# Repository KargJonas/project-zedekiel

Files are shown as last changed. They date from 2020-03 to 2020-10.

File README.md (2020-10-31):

# project-zedekiel
A pain-free 66% keyboard.

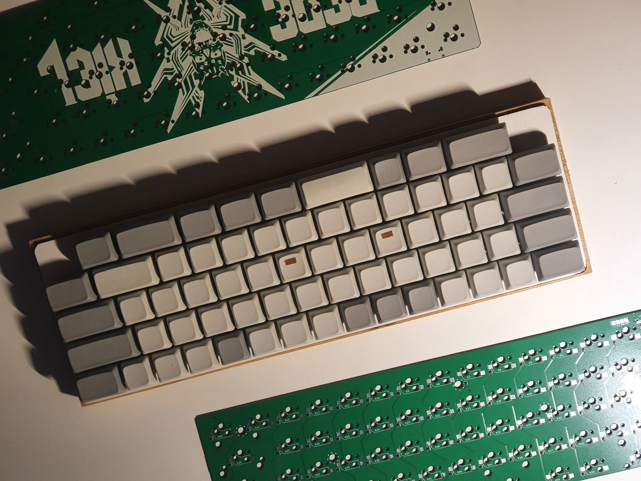
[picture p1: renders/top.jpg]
Built top view

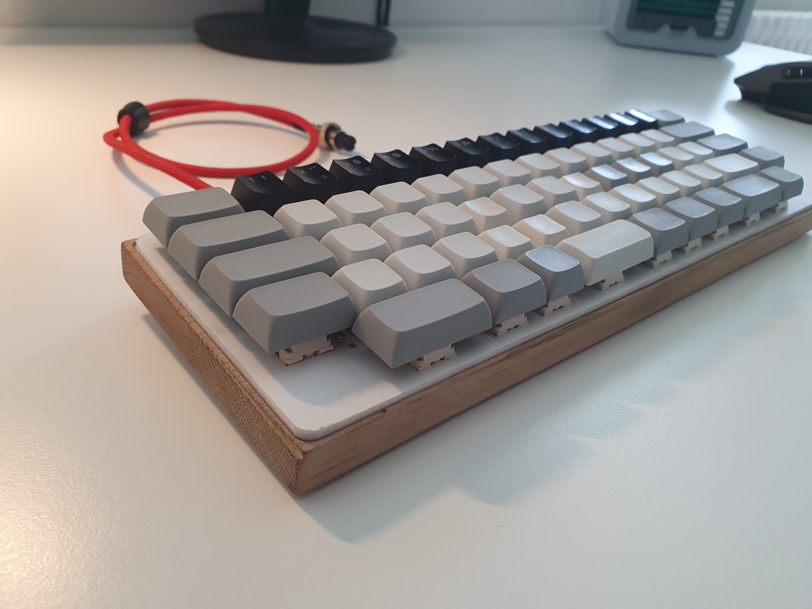
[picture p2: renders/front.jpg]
Built front view

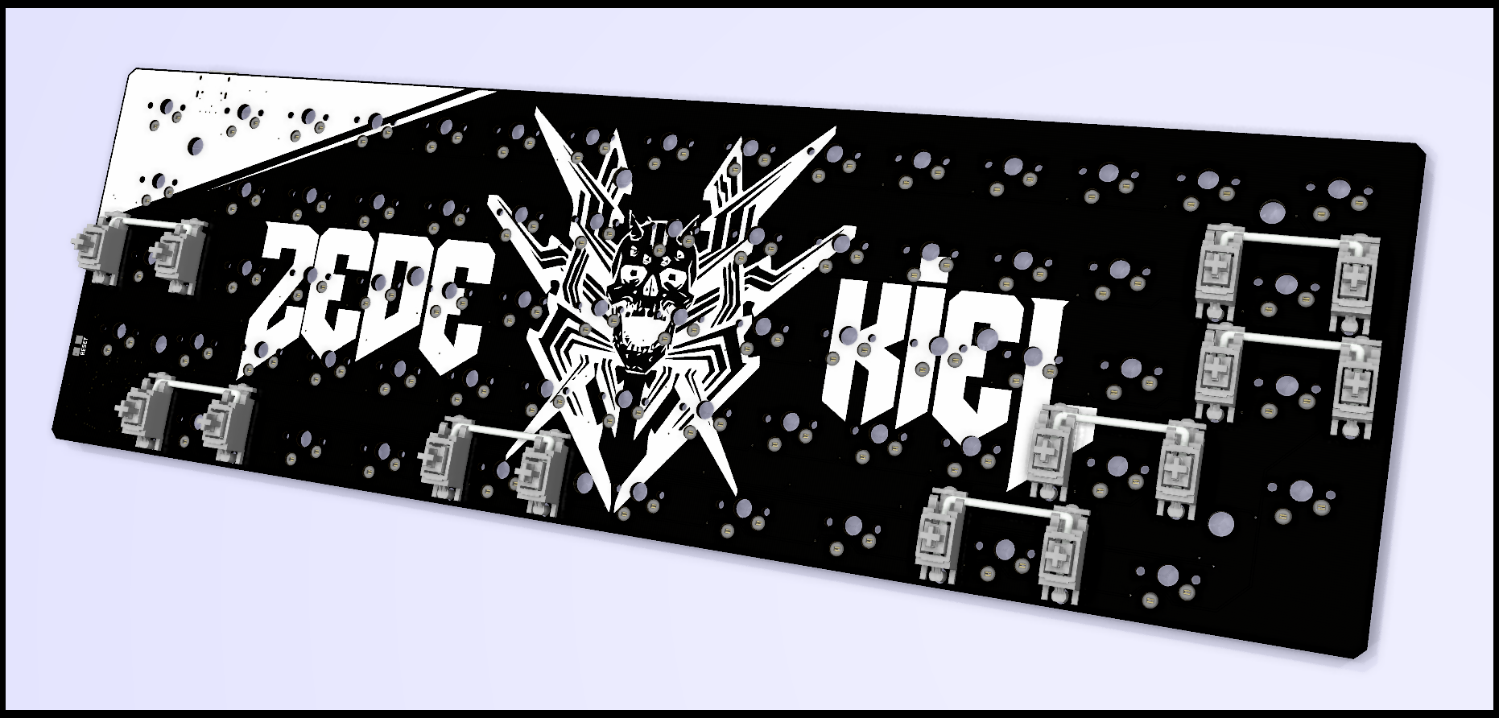
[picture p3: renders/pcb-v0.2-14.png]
Render

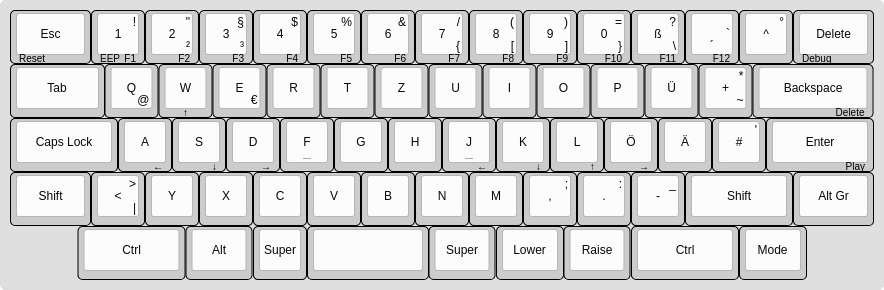
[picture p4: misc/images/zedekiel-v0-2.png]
Layout


## Flashing Guide
You will need linux for this (yes, when the keyboard is flashed, it will work in windows).
If you are using windows, you might want to take a look at [WSL](https://docs.microsoft.com/en-us/windows/wsl/).

- Clone the Zedekiel QMK fork: `git clone git@github.com:KargJonas/qmk_firmware`
- Open the directory: `cd qmk_firmware`
- Compile and flash Zedekiel default layout: `sudo make zedekiel:default:dfu`

If all goes well, your keyboard should now be ready to use.

## Tools used to make this
- KiCad
- LibreOffice
- LibreCad
- FreeCad
- GIMP
- QMK
- [www.keyboard-layout-editor.com](http://www.keyboard-layout-editor.com/)
- [builder.swillkb.com](http://builder.swillkb.com/)
- [qmk.fm/converter](https://qmk.fm/converter/)
- [www.engbedded.com/fusecalc](https://www.engbedded.com/fusecalc/)

## Resources
- [Keyboard PCB Guide](https://github.com/ruiqimao/keyboard-pcb-guide)
- [keebfol.io List of custom MKs](https://keebfol.io/)
- [QMK Getting Started](https://github.com/qmk/qmk_firmware/blob/76189d9a282cc32bf2ff88a84a6374ebb8908433/docs/getting_started_introduction.md)
- [Understanding QMK](https://github.com/qmk/qmk_firmware/blob/76189d9a282cc32bf2ff88a84a6374ebb8908433/docs/understanding_qmk.md)
- [QMK Keyboard Support](https://beta.docs.qmk.fm/configurator/qmk-api/reference_configurator_support)
- [QMK Config Guide](https://beta.docs.qmk.fm/developing-qmk/c-development/hardware_avr)
- [QMK Keycodes](https://github.com/qmk/qmk_firmware/blob/76189d9a282cc32bf2ff88a84a6374ebb8908433/docs/keycodes.md)
- [QMK ISP Flashing Guide](https://beta.docs.qmk.fm/using-qmk/guides/keyboard-building/isp_flashing_guide)
- [DFU Explained](https://electronics.stackexchange.com/questions/299712/how-is-the-atmega32u4-chip-recognized-via-usb)
- (More in `/misc/resources` folder)

## List of small issues and solutions
- KiCad footprint update not reflecting in 3D viewer =>
  - "e" on footprint
  - Edit footprint from Library
  - Edit footprint properties with the symbol in the topbar of the footprint editor
  - Go back to the pcb editor
  - "e" on footprint
  - Update footprint
  - 3D viewer should automatically update the 3D model
- FreeCad CSV import "broken" => export with {TAB} as delimiter.

# More Pictures
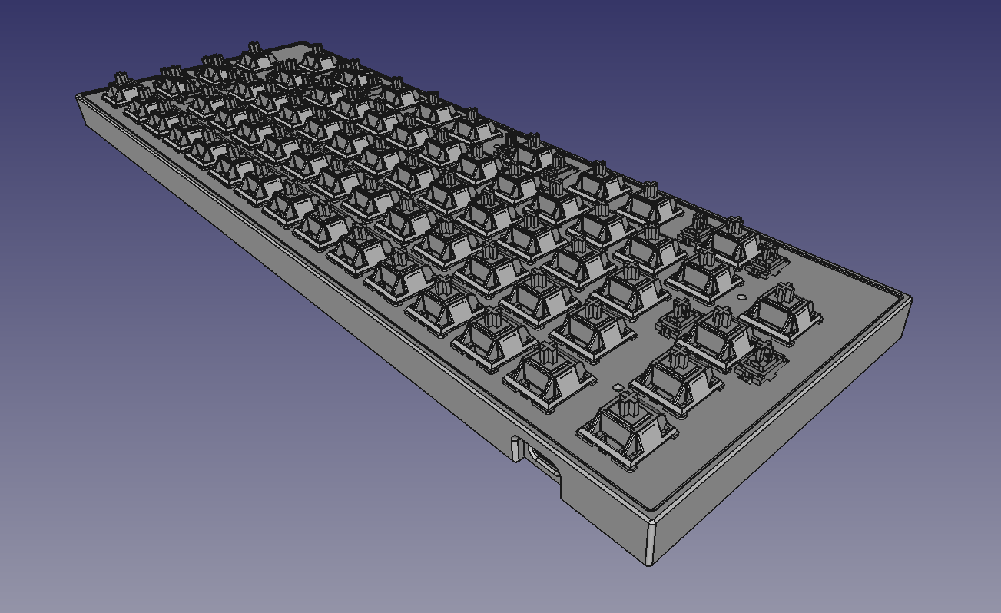
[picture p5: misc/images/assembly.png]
Assembly

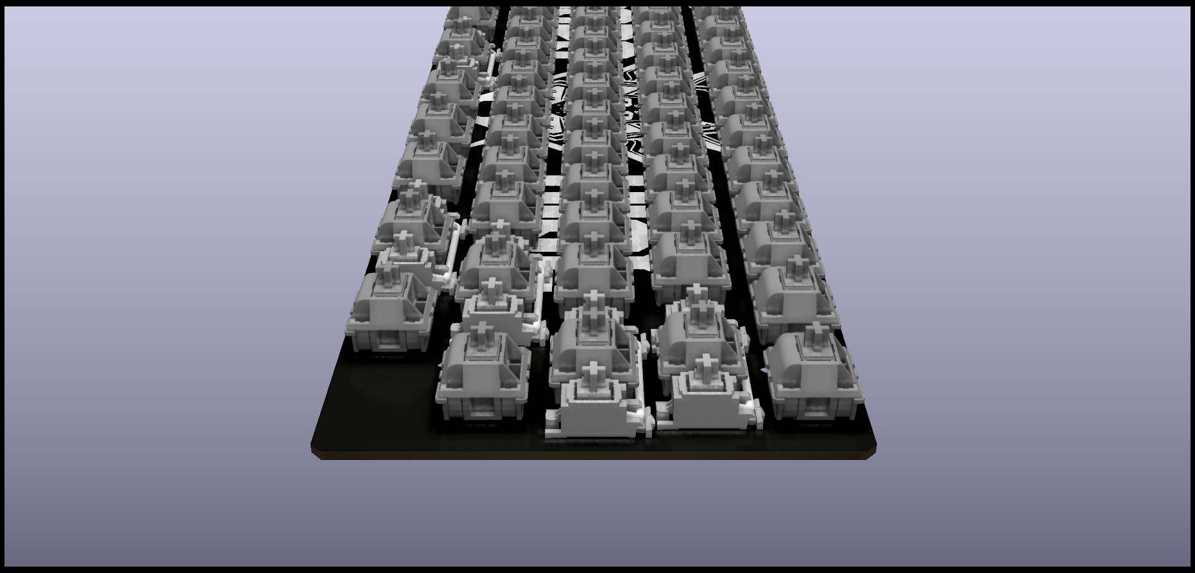
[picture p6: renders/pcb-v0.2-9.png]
Render

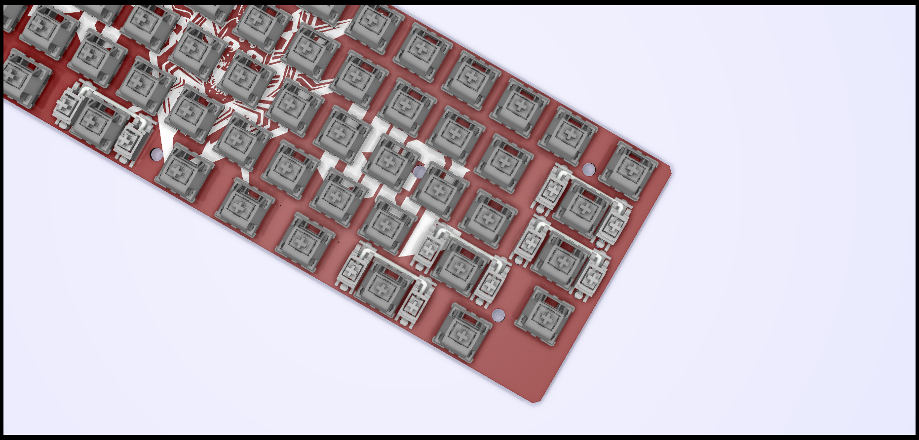
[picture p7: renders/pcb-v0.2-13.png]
Render

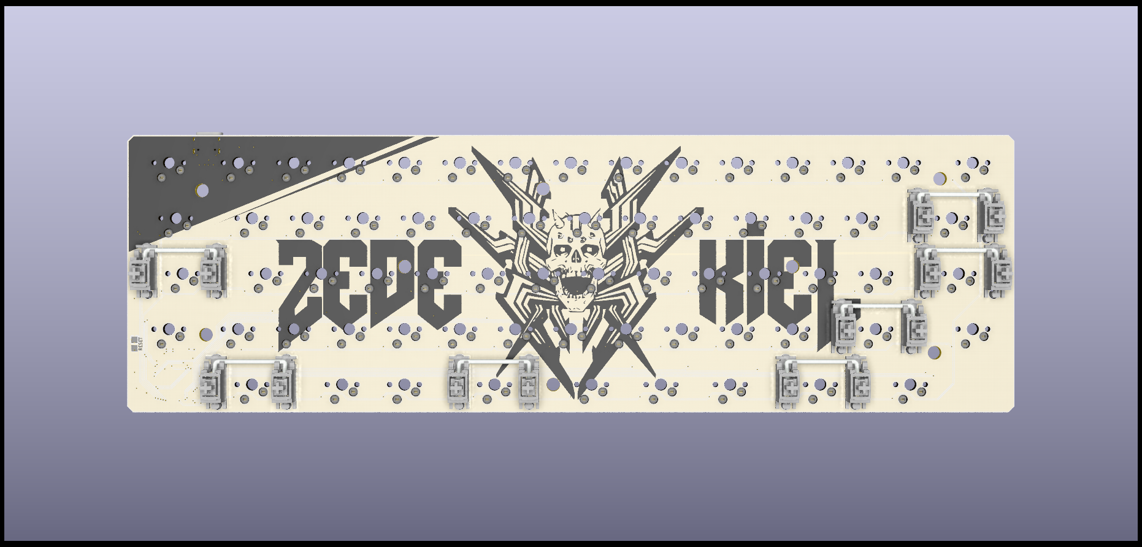
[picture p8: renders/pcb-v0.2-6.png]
Render

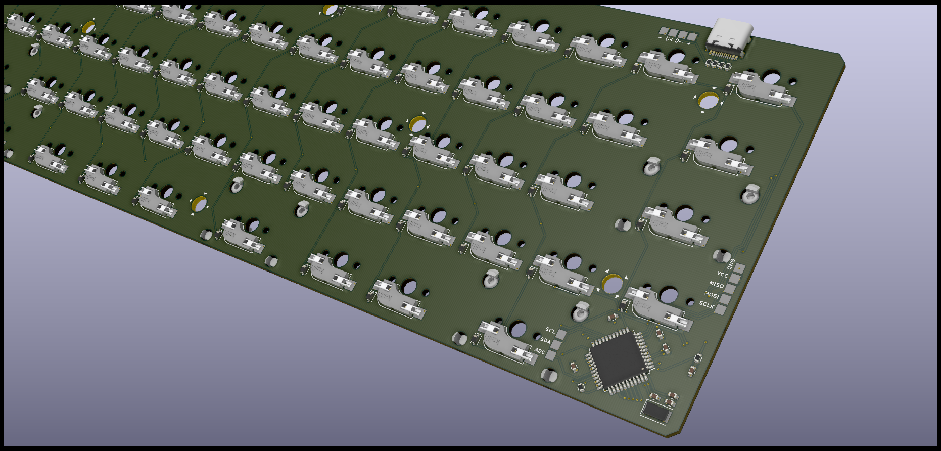
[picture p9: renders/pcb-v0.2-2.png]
Render

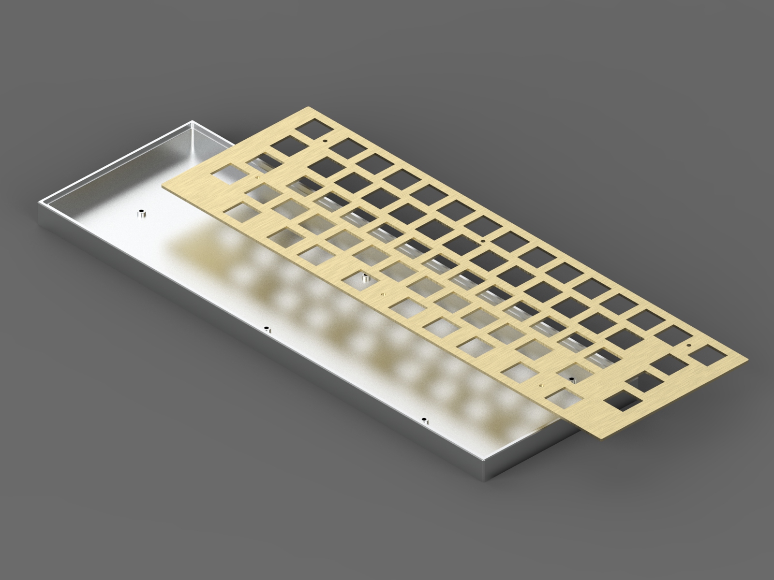
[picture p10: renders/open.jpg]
Render


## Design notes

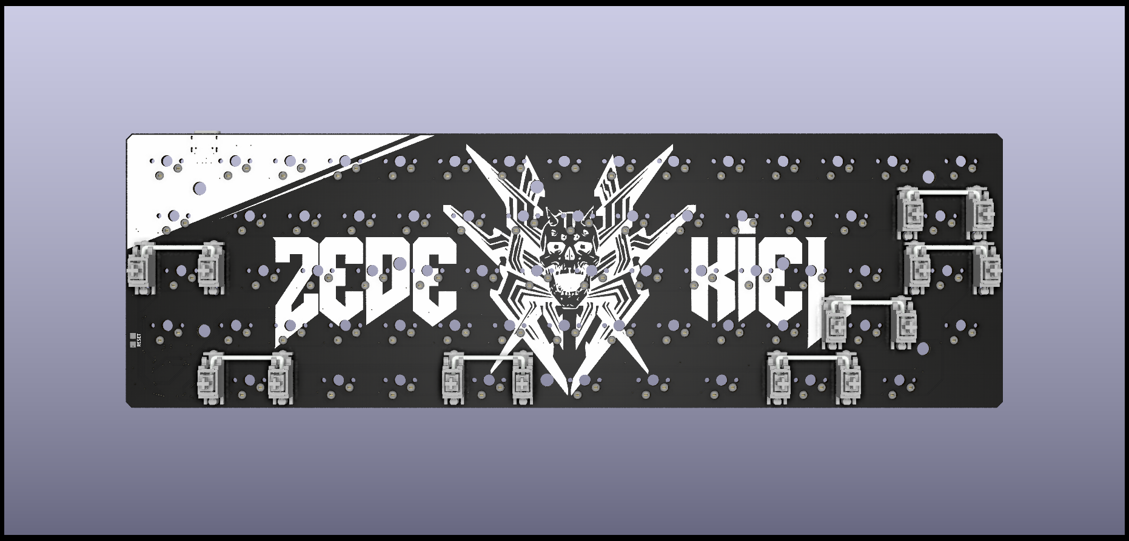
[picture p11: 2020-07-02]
renders/pcb-v0.2-7.png

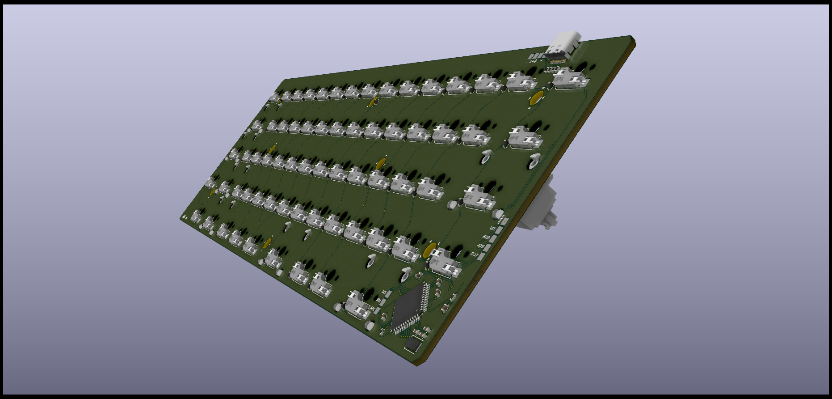
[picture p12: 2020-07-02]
renders/pcb-v0.2-1.png

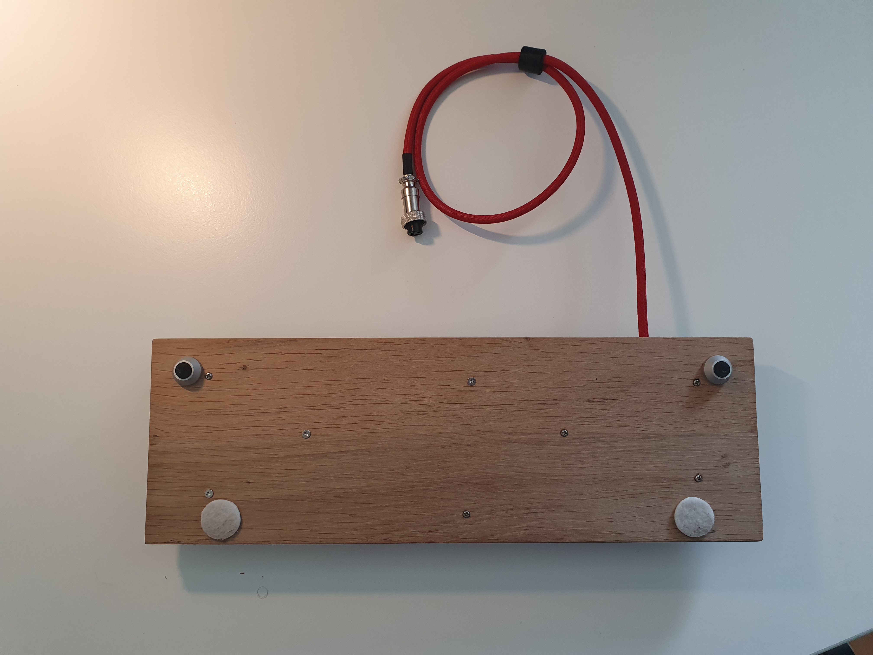
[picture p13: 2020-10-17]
misc/images/prototype/bottom.jpg

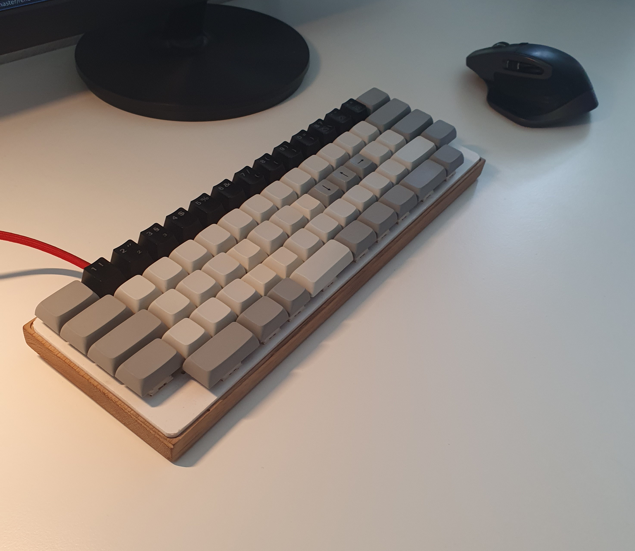
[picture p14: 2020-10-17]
misc/images/prototype/top-edge.jpg

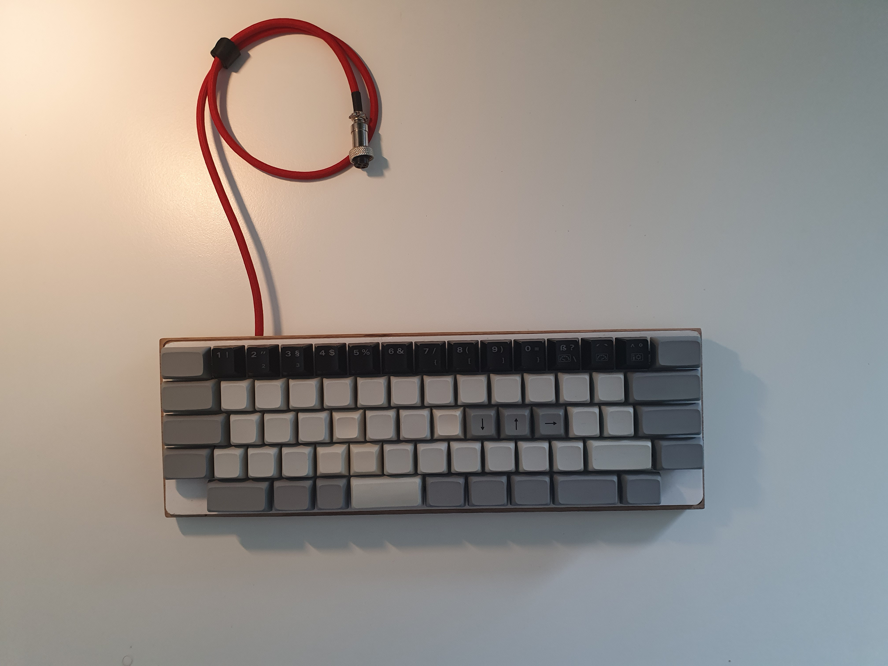
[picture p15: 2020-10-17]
misc/images/prototype/top-down.jpg

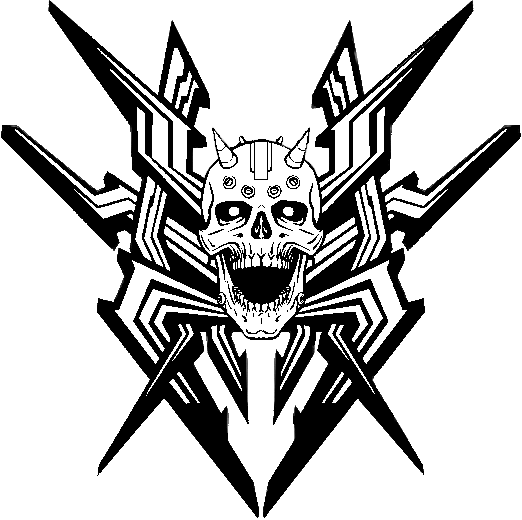
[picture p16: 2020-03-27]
misc/images/doom-converted-black.png

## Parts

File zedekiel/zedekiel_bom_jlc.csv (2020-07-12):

Comment | Designator | Footprint | LCSC Part #
1uF | C1 | C_0603 | C15849
22pF | C2,C3 | C_0603 | C1653
100nF | C4,C5,C6,C7 | C_0603 | C14663
4.7uF | C8 | C_0603 | C19666
1N4148WS | D1,D2,D3,D4,D5,D6,D7,D8,D9,D10,D11,D12,D13,D14,D15,D16,D17,D18,D19,D20,D21,D22,D23,D24,D25,D26,D27,D28,D29,D30,D31,D32,D33,D34,D35,D36,D37,D38,D39,D40,D41,D42,D43,D44,D45,D46,D47,D48,D49,D50,D51,D52,D53,D54,D55,D56,D57,D58,D59,D60,D61,D62,D63,D64,D65,D66 | D_SOD-323 | C57759
10K | R1,R6 | R_0603 | C25804
5.1K | R2,R3 | R_0603 | C23186
22 | R4,R5 | R_0603 | C23345
ATmega16U4-AU_(modified) | U1 | TQFP-44_10x10mm_Pitch0.8mm | C44854
16MHz | X1 | Crystal_SMD_5032-2pin_5.0x3.2mm | C112572

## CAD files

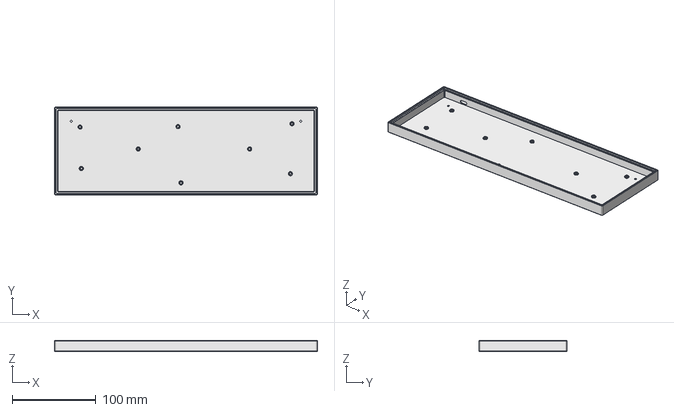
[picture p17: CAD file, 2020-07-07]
case/case-low.FCStd
314.0 x 105.0 x 13.5 mm

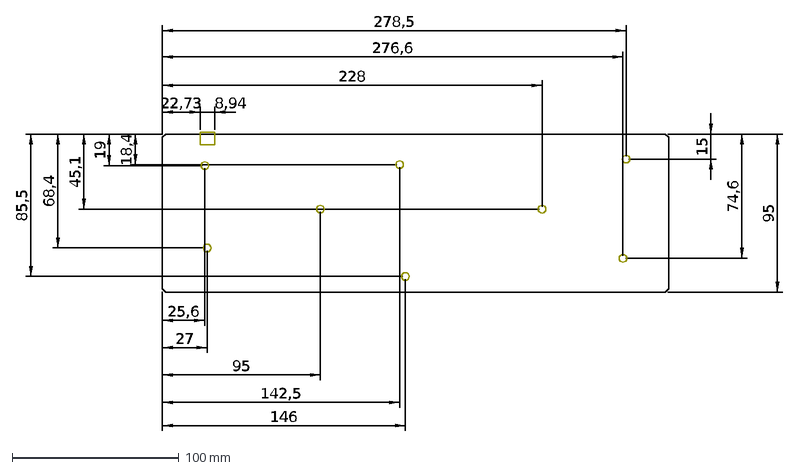
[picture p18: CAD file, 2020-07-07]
misc/documents/#pcb-sketch.dxf
18,4
19
15
45,1
74,6
68,4
85,5
95
22,73
8,94
25,6
27
142,5
146
228
276,6
278,5

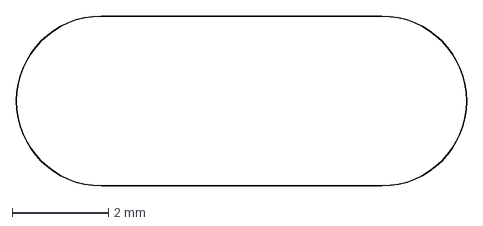
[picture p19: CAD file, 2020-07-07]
misc/usb-port-cutout-3.dxf
9.34 x 3.52 mm

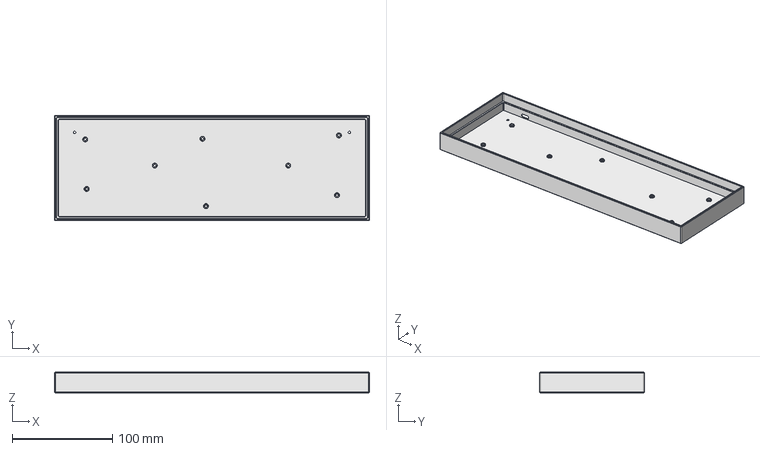
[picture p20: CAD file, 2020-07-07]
case/case-tall.FCStd
314.0 x 105.0 x 20.5 mm

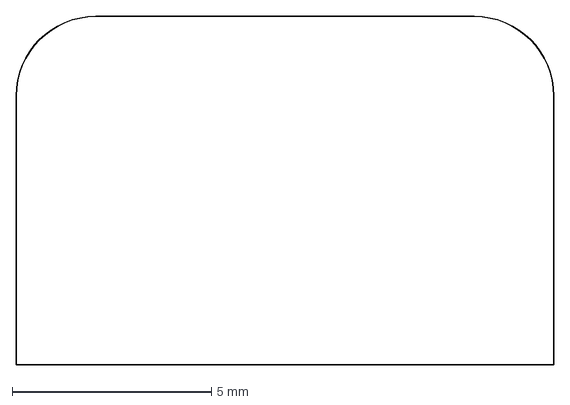
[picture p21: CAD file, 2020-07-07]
misc/usb-port-inset-2.dxf
13.5 x 8.74 mm

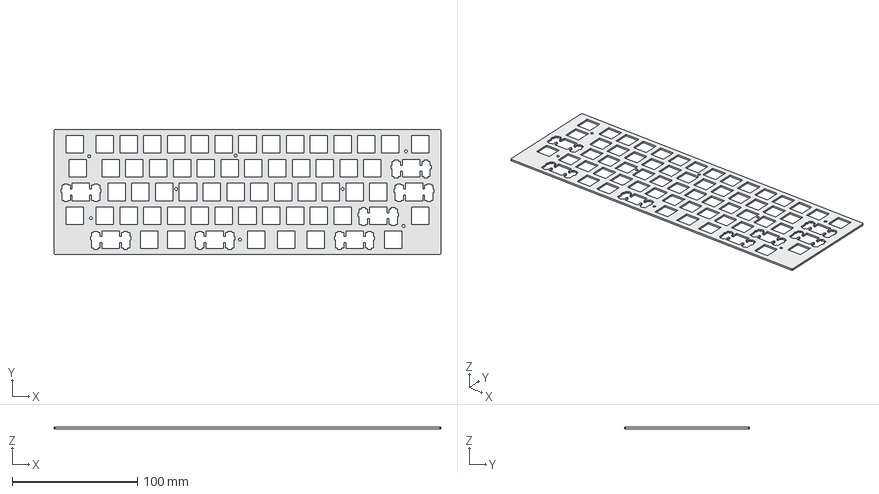
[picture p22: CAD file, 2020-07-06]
case/switch-plate.FCStd
309.0 x 100.0 x 1.50 mm

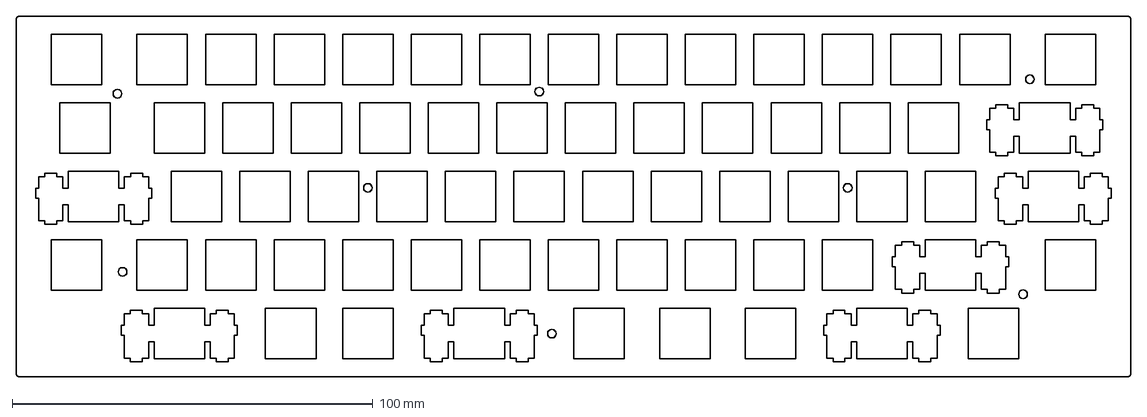
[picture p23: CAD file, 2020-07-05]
misc/switch-plate.dxf
309.0 x 100.0 mm

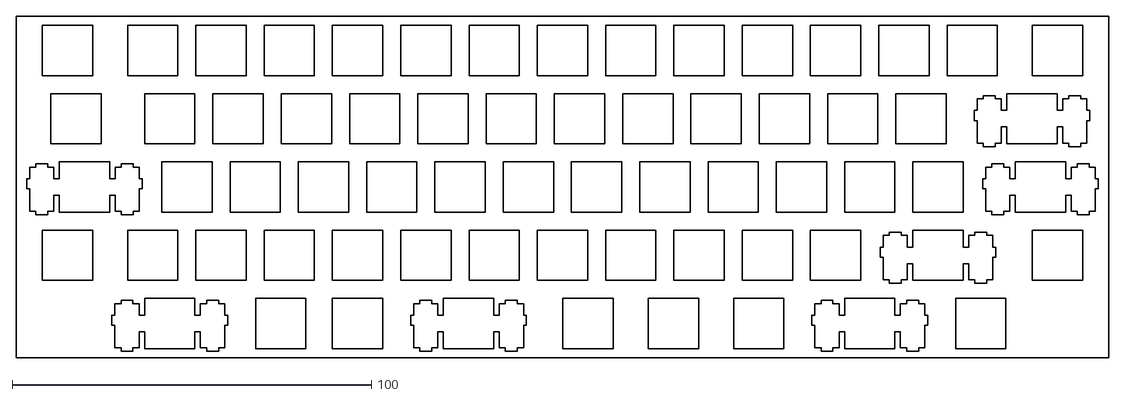
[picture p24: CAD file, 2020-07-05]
misc/switch-plate-raw.dxf
304.0 x 95.0

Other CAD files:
misc/documents/pcb-sketch.dxf

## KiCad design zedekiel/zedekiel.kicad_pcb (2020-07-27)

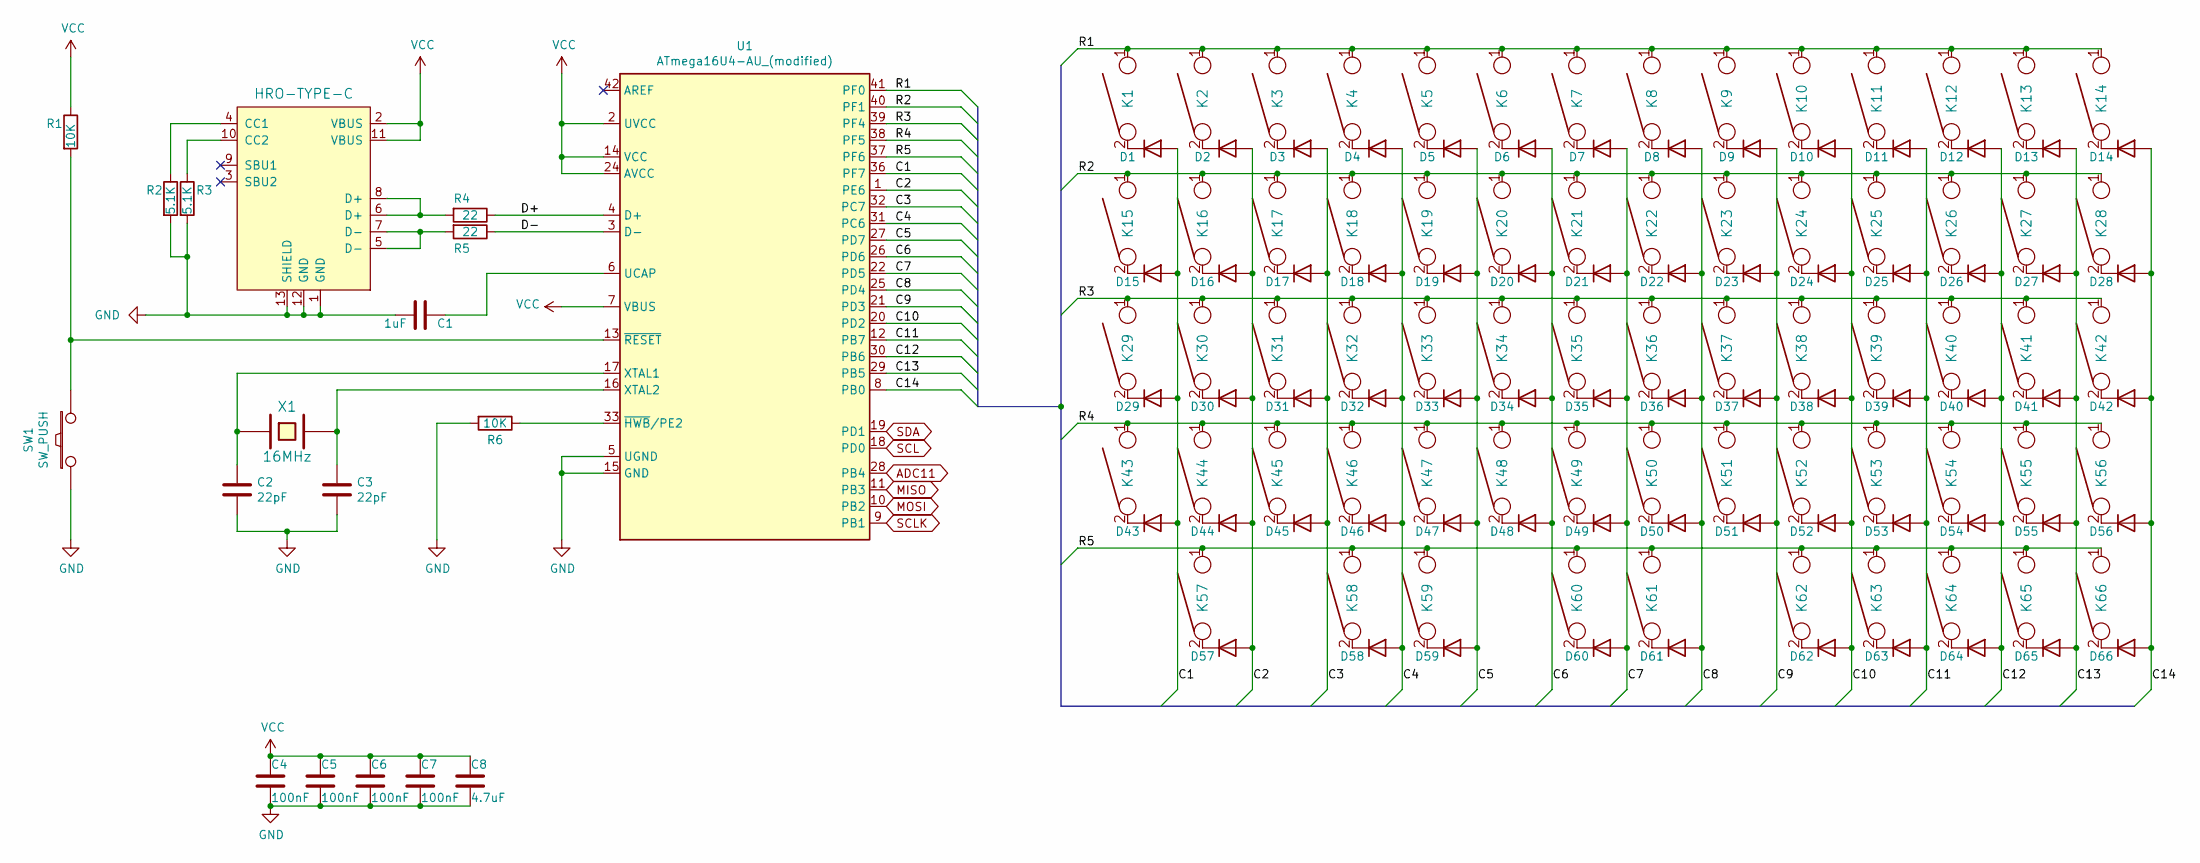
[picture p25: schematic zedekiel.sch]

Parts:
C1: 1uF; C_0603; LCSC C15849
C2, C3: 22pF; C_0603; LCSC C1653
C4, C5, C6, C7: 100nF; C_0603; LCSC C14663
C8: 4.7uF; C_0603; LCSC C19666
D1, D2, D3, D4, D5, D6, D7, D8, D9, D10, D11, D12, D13, D14, D15, D16, D17, D18, D19, D20, D21, D22, D23, D24, D25, D26, D27, D28, D29, D30, D31, D32, D33, D34, D35, D36, D37, D38, D39, D40, D41, D42, D43, D44, D45, D46, D47, D48, D49, D50, D51, D52, D53, D54, D55, D56, D57, D58, D59, D60, D61, D62, D63, D64, D65, D66: 1N4148WS; D_SOD-323; LCSC C57759
K1, K43, K56, K66: KEYSW; Kailh_socket_MX_1.50U
K2, K3, K4, K5, K6, K7, K8, K9, K10, K11, K12, K13, K14, K16, K17, K18, K19, K20, K21, K22, K23, K24, K25, K26, K27, K30, K31, K32, K33, K34, K35, K36, K37, K38, K39, K40, K41, K44, K45, K46, K47, K48, K49, K50, K51, K52, K53, K54, K59: KEYSW; Kailh_socket_MX_1.00U
K15: KEYSW; Kailh_socket_MX_1.75U
K28, K60: KEYSW; Kailh_socket_MX_2.25U
K29, K42, K55, K57, K64: KEYSW; Kailh_socket_MX_2.00U
K58, K61, K62, K63, K65: KEYSW; Kailh_socket_MX_1.25U
R1, R6: 10K; R_0603; LCSC C25804
R2, R3: 5.1K; R_0603; LCSC C23186
R4, R5: 22; R_0603; LCSC C23345
SW1: SW_PUSH; pad-button
U1: ATmega16U4-AU_(modified); TQFP-44_10x10mm_Pitch0.8mm; LCSC C44854
USB1: HRO-TYPE-C; HRO-TYPE-C-31-M-12
X1: 16MHz; Crystal_SMD_5032-2pin_5.0x3.2mm; LCSC C112572

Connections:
/C1: D1.2 (A), D15.2 (A), D29.2 (A), D43.2 (A), U1.36 (PF7)
/C2: D2.2 (A), D16.2 (A), D30.2 (A), D44.2 (A), D57.2 (A), U1.1 (PE6)
/C3: D3.2 (A), D17.2 (A), D31.2 (A), D45.2 (A), U1.32 (PC7)
/C4: D4.2 (A), D18.2 (A), D32.2 (A), D46.2 (A), D58.2 (A), U1.31 (PC6)
/C5: D5.2 (A), D19.2 (A), D33.2 (A), D47.2 (A), D59.2 (A), U1.27 (PD7)
/C6: D6.2 (A), D20.2 (A), D34.2 (A), D48.2 (A), U1.26 (PD6)
/C7: D7.2 (A), D21.2 (A), D35.2 (A), D49.2 (A), D60.2 (A), U1.22 (PD5)
/C8: D8.2 (A), D22.2 (A), D36.2 (A), D50.2 (A), D61.2 (A), U1.25 (PD4)
/C9: D9.2 (A), D23.2 (A), D37.2 (A), D51.2 (A), U1.21 (PD3)
/C10: D10.2 (A), D24.2 (A), D38.2 (A), D52.2 (A), D62.2 (A), U1.20 (PD2)
/C11: D11.2 (A), D25.2 (A), D39.2 (A), D53.2 (A), D63.2 (A), U1.12 (PB7)
/C12: D12.2 (A), D26.2 (A), D40.2 (A), D54.2 (A), D64.2 (A), U1.30 (PB6)
/C13: D13.2 (A), D27.2 (A), D41.2 (A), D55.2 (A), D65.2 (A), U1.29 (PB5)
/C14: D14.2 (A), D28.2 (A), D42.2 (A), D56.2 (A), D66.2 (A), U1.8 (PB0)
/D+: R4.1, U1.4 (D+)
/D-: R5.1, U1.3 (D-)
/R1: K1.1, K2.1, K3.1, K4.1, K5.1, K6.1, K7.1, K8.1, K9.1, K10.1, K11.1, K12.1, K13.1, K14.1, U1.41 (PF0)
/R2: K15.1, K16.1, K17.1, K18.1, K19.1, K20.1, K21.1, K22.1, K23.1, K24.1, K25.1, K26.1, K27.1, K28.1, U1.40 (PF1)
/R3: K29.1, K30.1, K31.1, K32.1, K33.1, K34.1, K35.1, K36.1, K37.1, K38.1, K39.1, K40.1, K41.1, K42.1, U1.39 (PF4)
/R4: K43.1, K44.1, K45.1, K46.1, K47.1, K48.1, K49.1, K50.1, K51.1, K52.1, K53.1, K54.1, K55.1, K56.1, U1.38 (PF5)
/R5: K57.1, K58.1, K59.1, K60.1, K61.1, K62.1, K63.1, K64.1, K65.1, K66.1, U1.37 (PF6)
ADC11: U1.28 (PB4); also elsewhere on the board
GND: C1.2, C2.2, C3.2, C4.2, C5.2, C6.2, C7.2, C8.2, R2.2, R3.2, R6.2, SW1.1, U1.5 (UGND), U1.15 (GND), USB1.1 (GND), USB1.12 (GND), USB1.13 (SHIELD); also elsewhere on the board
MISO: U1.11 (PB3); also elsewhere on the board
MOSI: U1.10 (PB2); also elsewhere on the board
unnamed: C1.1, U1.6 (UCAP)
unnamed: C2.1, U1.17 (XTAL1), X1.1
unnamed: C3.1, U1.16 (XTAL2), X1.2
unnamed: D1.1 (K), K1.2
unnamed: D2.1 (K), K2.2
unnamed: D3.1 (K), K3.2
unnamed: D4.1 (K), K4.2
unnamed: D5.1 (K), K5.2
unnamed: D6.1 (K), K6.2
unnamed: D7.1 (K), K7.2
unnamed: D8.1 (K), K8.2
unnamed: D9.1 (K), K9.2
unnamed: D10.1 (K), K10.2
unnamed: D11.1 (K), K11.2
unnamed: D12.1 (K), K12.2
unnamed: D13.1 (K), K13.2
unnamed: D14.1 (K), K14.2
unnamed: D15.1 (K), K15.2
unnamed: D16.1 (K), K16.2
unnamed: D17.1 (K), K17.2
unnamed: D18.1 (K), K18.2
unnamed: D19.1 (K), K19.2
unnamed: D20.1 (K), K20.2
unnamed: D21.1 (K), K21.2
unnamed: D22.1 (K), K22.2
unnamed: D23.1 (K), K23.2
unnamed: D24.1 (K), K24.2
unnamed: D25.1 (K), K25.2
unnamed: D26.1 (K), K26.2
unnamed: D27.1 (K), K27.2
unnamed: D28.1 (K), K28.2
unnamed: D29.1 (K), K29.2
unnamed: D30.1 (K), K30.2
unnamed: D31.1 (K), K31.2
unnamed: D32.1 (K), K32.2
unnamed: D33.1 (K), K33.2
unnamed: D34.1 (K), K34.2
unnamed: D35.1 (K), K35.2
unnamed: D36.1 (K), K36.2
unnamed: D37.1 (K), K37.2
unnamed: D38.1 (K), K38.2
unnamed: D39.1 (K), K39.2
unnamed: D40.1 (K), K40.2
unnamed: D41.1 (K), K41.2
unnamed: D42.1 (K), K42.2
unnamed: D43.1 (K), K43.2
unnamed: D44.1 (K), K44.2
unnamed: D45.1 (K), K45.2
unnamed: D46.1 (K), K46.2
unnamed: D47.1 (K), K47.2
unnamed: D48.1 (K), K48.2
unnamed: D49.1 (K), K49.2
unnamed: D50.1 (K), K50.2
unnamed: D51.1 (K), K51.2
unnamed: D52.1 (K), K52.2
unnamed: D53.1 (K), K53.2
unnamed: D54.1 (K), K54.2
unnamed: D55.1 (K), K55.2
unnamed: D56.1 (K), K56.2
unnamed: D57.1 (K), K57.2
unnamed: D58.1 (K), K58.2
unnamed: D59.1 (K), K59.2
unnamed: D60.1 (K), K60.2
unnamed: D61.1 (K), K61.2
unnamed: D62.1 (K), K62.2
unnamed: D63.1 (K), K63.2
unnamed: D64.1 (K), K64.2
unnamed: D65.1 (K), K65.2
unnamed: D66.1 (K), K66.2
unnamed: R1.2, SW1.2, U1.13 (~RESET)
unnamed: R2.1, USB1.4 (CC1)
unnamed: R3.1, USB1.10 (CC2)
unnamed 97: R4.2, USB1.6 (D+), USB1.8 (D+); also elsewhere on the board
unnamed 98: R5.2, USB1.5 (D-), USB1.7 (D-); also elsewhere on the board
unnamed: R6.1, U1.33 (~HWB~/PE2)
SCL: U1.18 (PD0); also elsewhere on the board
SCLK: U1.9 (PB1); also elsewhere on the board
SDA: U1.19 (PD1); also elsewhere on the board
VCC: C4.1, C5.1, C6.1, C7.1, C8.1, R1.1, U1.2 (UVCC), U1.7 (VBUS), U1.14 (VCC), U1.24 (AVCC), USB1.2 (VBUS), USB1.11 (VBUS); also elsewhere on the board

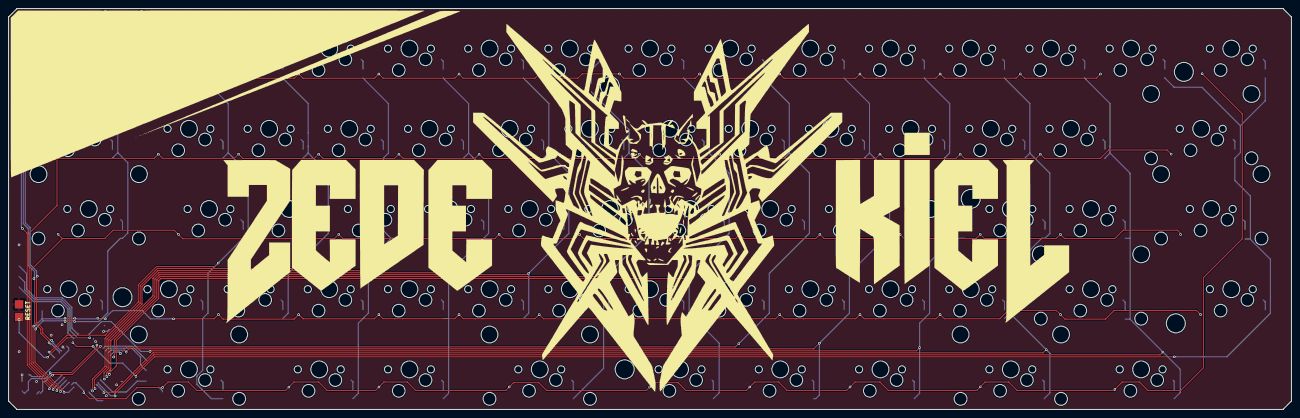
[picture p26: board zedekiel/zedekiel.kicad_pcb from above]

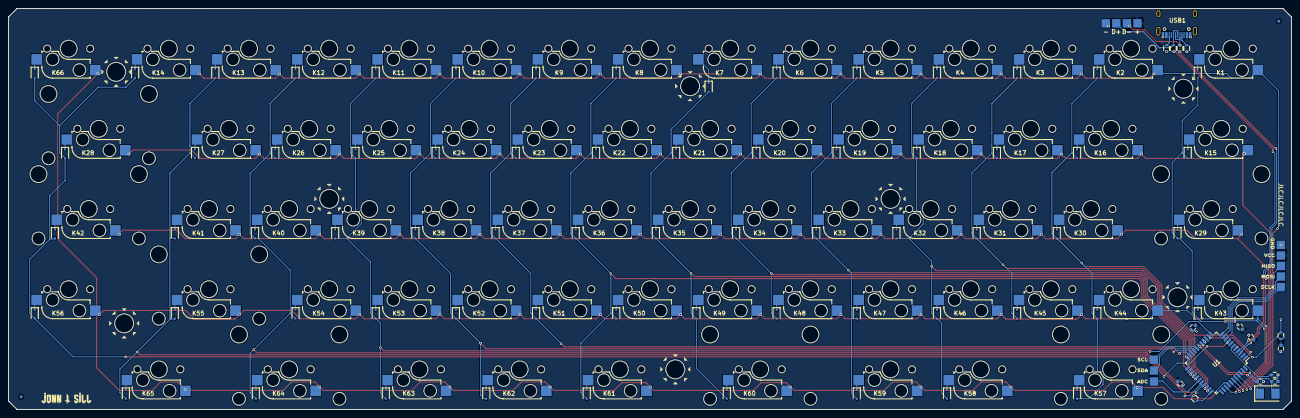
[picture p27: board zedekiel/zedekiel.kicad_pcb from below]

Board: 2 copper layers, 304.0 x 95.0 mm, 162 parts (95 on the bottom side), 104 nets.

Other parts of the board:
TP1, TP2, TP3, TP4, TP5, TP6, TP6#2, TP6#3, TP7, TP8, TP9, TP10: TestPoint; single-pad

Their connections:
ADC11: TP7.1; also elsewhere on the board
GND: TP4.1, TP6.1; also elsewhere on the board
MISO: TP8.1; also elsewhere on the board
MOSI: TP9.1; also elsewhere on the board
unnamed 97: TP2.1; also elsewhere on the board
unnamed 98: TP3.1; also elsewhere on the board
SCL: TP6#3.1; also elsewhere on the board
SCLK: TP10.1; also elsewhere on the board
SDA: TP5.1; also elsewhere on the board
VCC: TP1.1, TP6#2.1; also elsewhere on the board

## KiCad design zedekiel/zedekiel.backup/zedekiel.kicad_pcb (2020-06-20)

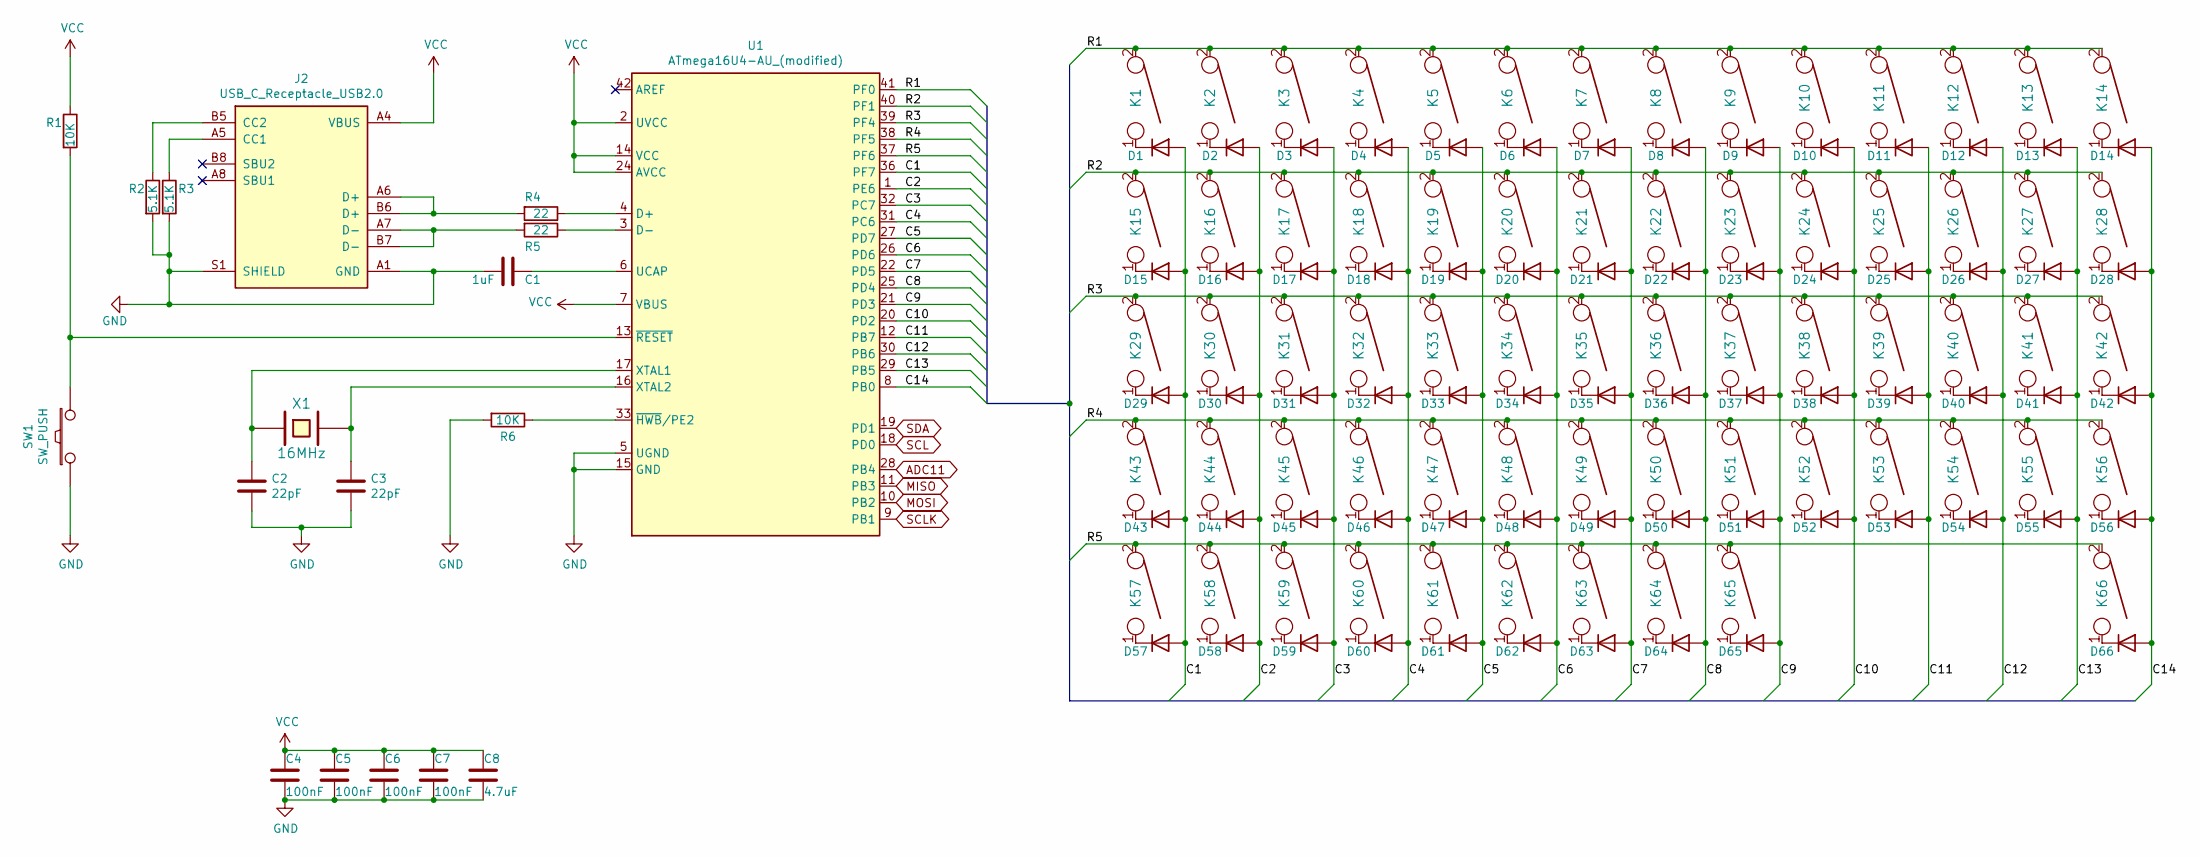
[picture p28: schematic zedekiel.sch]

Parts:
C1: 1uF; C_0603
C2, C3: 22pF; C_0603
C4, C5, C6, C7: 100nF; C_0603
C8: 4.7uF; C_0603
D1, D2, D3, D4, D5, D6, D7, D8, D9, D10, D11, D12, D13, D14, D15, D16, D17, D18, D19, D20, D21, D22, D23, D24, D25, D26, D27, D28, D29, D30, D31, D32, D33, D34, D35, D36, D37, D38, D39, D40, D41, D42, D43, D44, D45, D46, D47, D48, D49, D50, D51, D52, D53, D54, D55, D56, D57, D58, D59, D60, D61, D62, D63, D64, D65, D66: 1N4148WS; D_SOD-323
J2: USB_C_Receptacle_USB2.0; USB_C_Receptacle_Amphenol_12401548E4-2A
K1, K43, K56, K66: KEYSW; Kailh_socket_MX_1.50U
K2, K3, K4, K5, K6, K7, K8, K9, K10, K11, K12, K13, K14, K16, K17, K18, K19, K20, K21, K22, K23, K24, K25, K26, K27, K30, K31, K32, K33, K34, K35, K36, K37, K38, K39, K40, K41, K44, K45, K46, K47, K48, K49, K50, K51, K52, K53, K54, K59: KEYSW; Kailh_socket_MX_1.00U
K15: KEYSW; Kailh_socket_MX_1.75U
K28, K60: KEYSW; Kailh_socket_MX_2.25U
K29, K42, K55, K57, K64: KEYSW; Kailh_socket_MX_2.00U
K58, K61, K62, K63, K65: KEYSW; Kailh_socket_MX_1.25U
R1, R6: 10K; R_0603
R2, R3: 5.1K; R_0603
R4, R5: 22; R_0603
SW1: SW_PUSH; pad-button
U1: ATmega16U4-AU_(modified); TQFP-44_10x10mm_Pitch0.8mm
X1: 16MHz; Crystal_SMD_5032-2pin_5.0x3.2mm

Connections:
/C1: D1.2 (A), D15.2 (A), D29.2 (A), D43.2 (A), D57.2 (A), U1.36 (PF7)
/C2: D2.2 (A), D16.2 (A), D30.2 (A), D44.2 (A), D58.2 (A), U1.1 (PE6)
/C3: D3.2 (A), D17.2 (A), D31.2 (A), D45.2 (A), D59.2 (A), U1.32 (PC7)
/C4: D4.2 (A), D18.2 (A), D32.2 (A), D46.2 (A), D60.2 (A), U1.31 (PC6)
/C5: D5.2 (A), D19.2 (A), D33.2 (A), D47.2 (A), D61.2 (A), U1.27 (PD7)
/C6: D6.2 (A), D20.2 (A), D34.2 (A), D48.2 (A), D62.2 (A), U1.26 (PD6)
/C7: D7.2 (A), D21.2 (A), D35.2 (A), D49.2 (A), D63.2 (A), U1.22 (PD5)
/C8: D8.2 (A), D22.2 (A), D36.2 (A), D50.2 (A), D64.2 (A), U1.25 (PD4)
/C9: D9.2 (A), D23.2 (A), D37.2 (A), D51.2 (A), D65.2 (A), U1.21 (PD3)
/C10: D10.2 (A), D24.2 (A), D38.2 (A), D52.2 (A), U1.20 (PD2)
/C11: D11.2 (A), D25.2 (A), D39.2 (A), D53.2 (A), U1.12 (PB7)
/C12: D12.2 (A), D26.2 (A), D40.2 (A), D54.2 (A), U1.30 (PB6)
/C13: D13.2 (A), D27.2 (A), D41.2 (A), D55.2 (A), U1.29 (PB5)
/C14: D14.2 (A), D28.2 (A), D42.2 (A), D56.2 (A), D66.2 (A), U1.8 (PB0)
/R1: K1.2, K2.2, K3.2, K4.2, K5.2, K6.2, K7.2, K8.2, K9.2, K10.2, K11.2, K12.2, K13.2, K14.2, U1.41 (PF0)
/R2: K15.2, K16.2, K17.2, K18.2, K19.2, K20.2, K21.2, K22.2, K23.2, K24.2, K25.2, K26.2, K27.2, K28.2, U1.40 (PF1)
/R3: K29.2, K30.2, K31.2, K32.2, K33.2, K34.2, K35.2, K36.2, K37.2, K38.2, K39.2, K40.2, K41.2, K42.2, U1.39 (PF4)
/R4: K43.2, K44.2, K45.2, K46.2, K47.2, K48.2, K49.2, K50.2, K51.2, K52.2, K53.2, K54.2, K55.2, K56.2, U1.38 (PF5)
/R5: K57.2, K58.2, K59.2, K60.2, K61.2, K62.2, K63.2, K64.2, K65.2, K66.2, U1.37 (PF6)
ADC11: U1.28 (PB4)
GND: C1.2, C2.2, C3.2, C4.2, C5.2, C6.2, C7.2, C8.2, J2.A1 (GND), J2.S1 (SHIELD), R2.2, R3.2, R6.2, SW1.1, U1.5 (UGND), U1.15 (GND)
MISO: U1.11 (PB3)
MOSI: U1.10 (PB2)
unnamed: C1.1, U1.6 (UCAP)
unnamed: C2.1, U1.17 (XTAL1), X1.1
unnamed: C3.1, U1.16 (XTAL2), X1.2
unnamed: D1.1 (K), K1.1
unnamed: D2.1 (K), K2.1
unnamed: D3.1 (K), K3.1
unnamed: D4.1 (K), K4.1
unnamed: D5.1 (K), K5.1
unnamed: D6.1 (K), K6.1
unnamed: D7.1 (K), K7.1
unnamed: D8.1 (K), K8.1
unnamed: D9.1 (K), K9.1
unnamed: D10.1 (K), K10.1
unnamed: D11.1 (K), K11.1
unnamed: D12.1 (K), K12.1
unnamed: D13.1 (K), K13.1
unnamed: D14.1 (K), K14.1
unnamed: D15.1 (K), K15.1
unnamed: D16.1 (K), K16.1
unnamed: D17.1 (K), K17.1
unnamed: D18.1 (K), K18.1
unnamed: D19.1 (K), K19.1
unnamed: D20.1 (K), K20.1
unnamed: D21.1 (K), K21.1
unnamed: D22.1 (K), K22.1
unnamed: D23.1 (K), K23.1
unnamed: D24.1 (K), K24.1
unnamed: D25.1 (K), K25.1
unnamed: D26.1 (K), K26.1
unnamed: D27.1 (K), K27.1
unnamed: D28.1 (K), K28.1
unnamed: D29.1 (K), K29.1
unnamed: D30.1 (K), K30.1
unnamed: D31.1 (K), K31.1
unnamed: D32.1 (K), K32.1
unnamed: D33.1 (K), K33.1
unnamed: D34.1 (K), K34.1
unnamed: D35.1 (K), K35.1
unnamed: D36.1 (K), K36.1
unnamed: D37.1 (K), K37.1
unnamed: D38.1 (K), K38.1
unnamed: D39.1 (K), K39.1
unnamed: D40.1 (K), K40.1
unnamed: D41.1 (K), K41.1
unnamed: D42.1 (K), K42.1
unnamed: D43.1 (K), K43.1
unnamed: D44.1 (K), K44.1
unnamed: D45.1 (K), K45.1
unnamed: D46.1 (K), K46.1
unnamed: D47.1 (K), K47.1
unnamed: D48.1 (K), K48.1
unnamed: D49.1 (K), K49.1
unnamed: D50.1 (K), K50.1
unnamed: D51.1 (K), K51.1
unnamed: D52.1 (K), K52.1
unnamed: D53.1 (K), K53.1
unnamed: D54.1 (K), K54.1
unnamed: D55.1 (K), K55.1
unnamed: D56.1 (K), K56.1
unnamed: D57.1 (K), K57.1
unnamed: D58.1 (K), K58.1
unnamed: D59.1 (K), K59.1
unnamed: D60.1 (K), K60.1
unnamed: D61.1 (K), K61.1
unnamed: D62.1 (K), K62.1
unnamed: D63.1 (K), K63.1
unnamed: D64.1 (K), K64.1
unnamed: D65.1 (K), K65.1
unnamed: D66.1 (K), K66.1
unnamed: J2.A5 (CC1), R3.1
unnamed: J2.A6 (D+), J2.B6 (D+), R4.2
unnamed: J2.A7 (D-), J2.B7 (D-), R5.2
unnamed: J2.B5 (CC2), R2.1
unnamed: R1.2, SW1.2, U1.13 (~RESET)
unnamed: R4.1, U1.4 (D+)
unnamed: R5.1, U1.3 (D-)
unnamed: R6.1, U1.33 (~HWB~/PE2)
SCL: U1.18 (PD0)
SCLK: U1.9 (PB1)
SDA: U1.19 (PD1)
VCC: C4.1, C5.1, C6.1, C7.1, C8.1, J2.A4 (VBUS), R1.1, U1.2 (UVCC), U1.7 (VBUS), U1.14 (VCC), U1.24 (AVCC)

Board: 2 copper layers, 150 parts (0 on the bottom side), 98 nets, no tracks yet.

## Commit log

2020-03-29 Added some stl files
    [case-bottom-extended-top.obj, case-bottom-extended-top.stl, case-plate.stl]
2020-04-06 Rounding for the screw protusions, foot part
    [case-bottom-extended-top.obj, case-bottom-extended-top.stl, case-plate.stl]
2020-04-23 Wood case, misc changes
2020-06-10 work on schematic/pcb
    [zedekiel.kicad_pcb, zedekiel.sch]
2020-06-20 Custom Footprints. Work in PCB.
    [zedekiel.kicad_pcb, zedekiel.sch]
2020-06-20 Diodes and sockets in place
    [zedekiel.kicad_pcb, zedekiel.sch]
2020-06-20 Holes and stabilizers
    [keycap-sizes.ods, zedekiel.kicad_pcb, zedekiel.sch]
2020-06-21 Routing started.
    [zedekiel.kicad_pcb, zedekiel.sch]
2020-06-21 Routing. Fixed a moved socket.
    [zedekiel.kicad_pcb, zedekiel.sch]
2020-06-21 Fixed another socket
    [zedekiel.kicad_pcb]
2020-06-21 Progress, I guess..
    [zedekiel.kicad_pcb, zedekiel.sch]
2020-06-24 working on better routing
    [zedekiel.kicad_pcb]
2020-06-24 better routing for the switch matrix
    [zedekiel.kicad_pcb]
2020-06-26 more routing
    [zedekiel.kicad_pcb, zedekiel.sch]
2020-06-26 routing improvements
    [zedekiel.kicad_pcb]
2020-06-27 almost done with routing
    [zedekiel.kicad_pcb]
2020-06-29 basically done with routing
    [zedekiel.kicad_pcb]
2020-06-30 done with routing
    [zedekiel.kicad_pcb]
2020-06-30 labeling & silk screen art
    [zedekiel.kicad_pcb]
2020-07-01 starting to add 3d models
    [Kailh Hotswap MX v22.step, Stabilizer - close.STEP]
2020-07-02 added some more models
    [Atmega32u4 v4.step, SC-76A.stp, csmd-0603_l1-6_w0-81_h0-86.stp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]
2020-07-02 project tree restructured, finished adding models
    [zedekiel.kicad_pcb, zedekiel.sch]
2020-07-02 added the switch position document
    [switch-model-position.ods]
2020-07-02 added a librecad scketch of the pcb
    [pcb-hole-positions.ods, pcb-sketch.dxf, zedekiel.kicad_pcb]
2020-07-02 cleaned up the project, added a readme
    [keycap-sizes.ods, pcb-hole-positions.ods, pcb-sketch.dxf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]
2020-07-02 added versions of sockets with/without switches
    [zedekiel.kicad_pcb]
2020-07-04 proper passhthough holes, better hole indicators, updated 3d model paths, freecad export of pcb
    [#pcb-sketch.dxf, zedekiel.kicad_pcb]
2020-07-05 designing the new case
    [#pcb-sketch.dxf, case-assembly.cfg, case.FCStd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]
2020-07-05 low case finished, test assembly
    [#pcb-sketch.dxf, case.FCStd, dimensions.ods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]
2020-07-05 switch plate, assembly, render attempt
    [#pcb-sketch.dxf, hole-positions.csv, switch-plate-raw.dxf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]
2020-07-06 progress on the case
    [case.FCStd, case.backup.FCStd, switch-plate.FCStd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]
2020-07-07 finished the case, minor change on pcb
    [#pcb-sketch.dxf, case-low.FCStd, case-tall.FCStd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]
2020-07-07 cleaned up the filetree a bit
    [case.FCStd, case.backup.FCStd, usb-port-cutout-2.dxf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]
2020-07-08 getting the pcb ready for manufacture
    [zedekiel-B_Cu.gbr, zedekiel-B_Mask.gbr, zedekiel-B_Paste.gbr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]
2020-07-10 minor changes
    [zedekiel.kicad_pcb]
2020-07-12 trying to get the assembly files to work
    [zedekiel-B_Cu.gbr, zedekiel-B_Mask.gbr, zedekiel-B_Paste.gbr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]
2020-07-12 got a working manufacturing export
    [zedekiel-B_Cu.gbr, zedekiel-B_Mask.gbr, zedekiel-B_Paste.gbr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]
2020-07-27 Fixed a problem on the pcb, updated readme
    [zedekiel.kicad_pcb]
2020-10-31 Added images of the working prototype
